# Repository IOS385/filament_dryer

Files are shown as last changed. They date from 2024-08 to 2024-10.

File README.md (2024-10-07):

# 3D Printer Filament Dryer Project
---
<p align="center">
Dryer
</p>

---
This project involves the development of a PCB designed to integrate the **Franzininho C0** with various interfaces for power, sensor reading, and load actuation.
---
<p align="center">
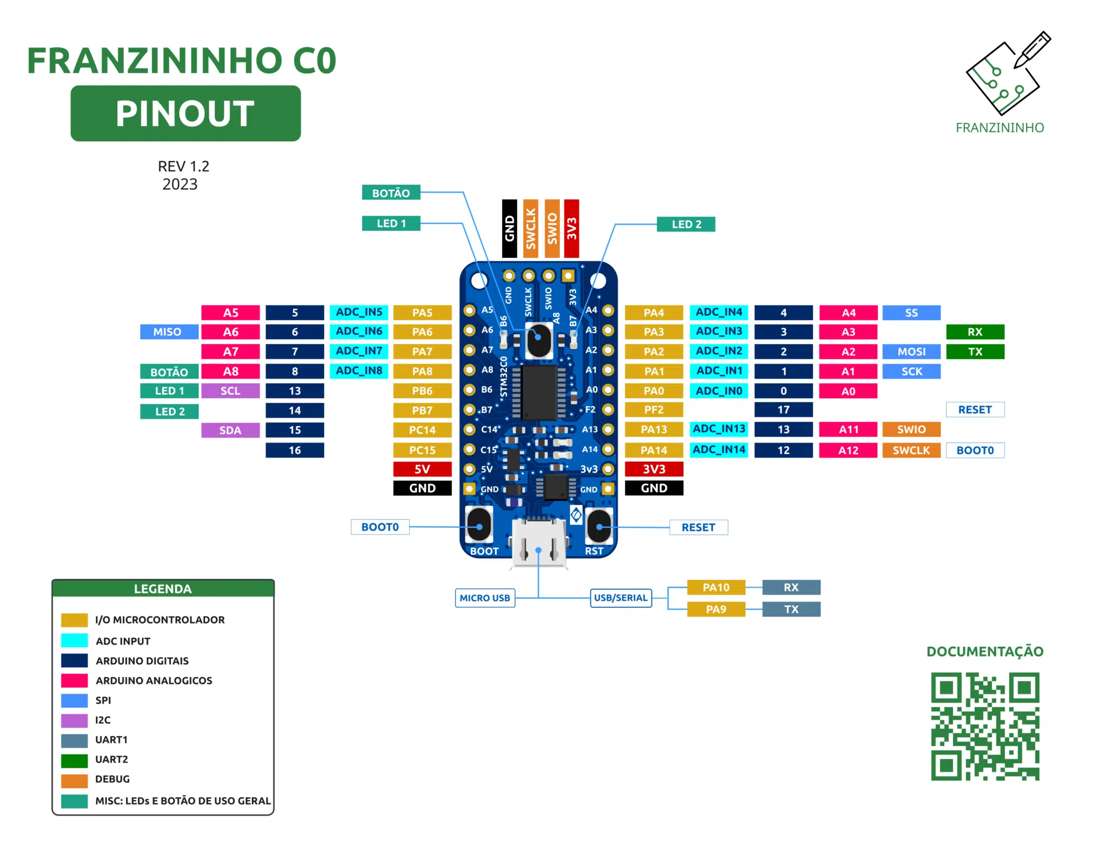
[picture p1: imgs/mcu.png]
Franzininho

</p>

---
## Key Features:
- Mosfet Driver to DC loads
- AC Driver to SSR control and ZeroCrossing detection
- Interface to LCD Display with I2C
- Relay Driver to AC or DC loads
- Analog temperature sensor with External NTC
- Digital temperature and humidity sensor (DHT22 or equivalent)
- 4x buttons to customizable functions (Can be external)

**Note:** This is a flexible project that can be used in other applications, such as:

- **Smart thermostat**: Control heating and cooling systems based on temperature and humidity readings.
- **Greenhouse automation**: Manage humidity, temperature, and lighting for plant growth.
- **Water heater controller**: Regulate the temperature of water in residential or industrial settings.
- **Home automation**: Control devices like fans, lights, or appliances using sensor inputs.
- **Aquarium climate controller**: Maintain stable temperatures and monitor water quality in aquariums.
- **Dehumidifier control**: Automatically manage a dehumidifier based on humidity sensor readings.
- **Food dehydrator**: Control heating elements to dry food for preservation.

The only limit is your creativity.

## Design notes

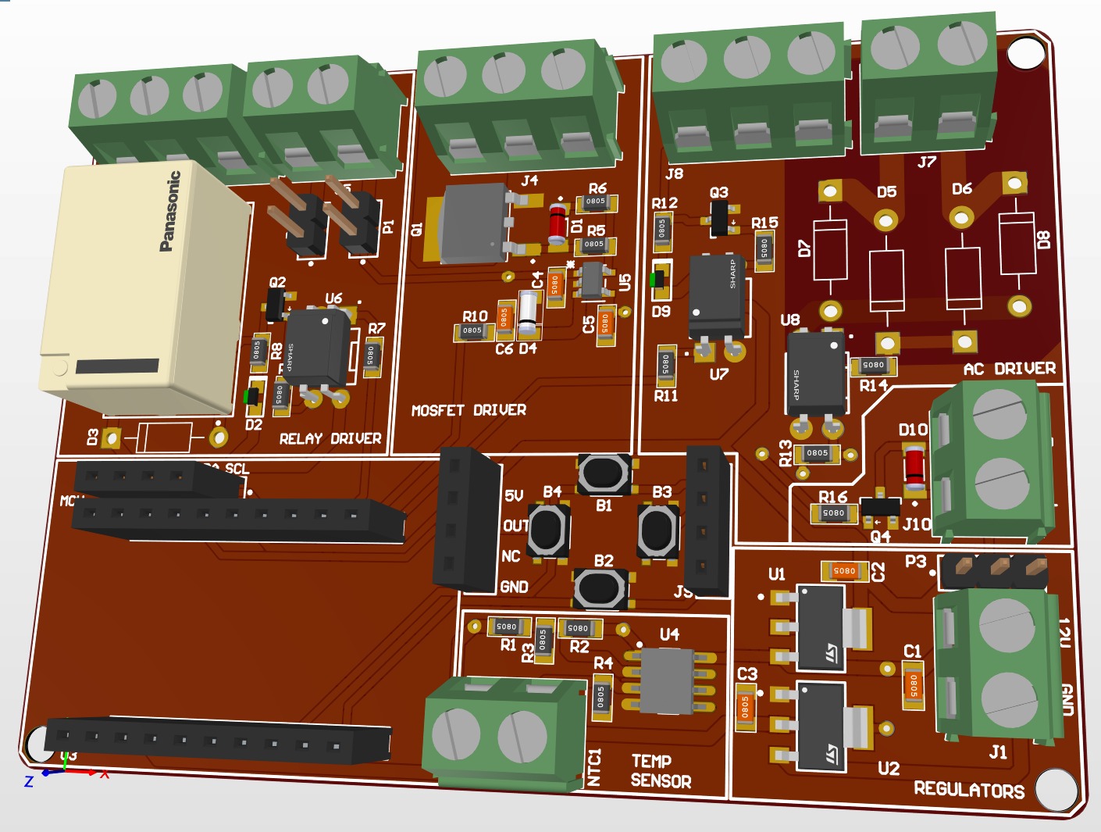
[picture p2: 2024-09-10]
imgs/pcb.jpeg

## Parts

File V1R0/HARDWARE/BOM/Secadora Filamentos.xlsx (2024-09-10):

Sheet: Secadora Filamentos
Name | Designator | Description | Quantity | Manufacturer 1 | Manufacturer Part Number 1
434133025816 | B1, B2, B3, B4 | 434133025816 Tactile Switch, 0.05A, 16Vdc, 160Gf, Smd Rohs Compliant: Yes |Wurth Elektronik 434133025816 | 4 | Wurth Electronics | 434133025816
1µF | C1, C2, C3, C4, C5, C6 | CAP CER 1UF 25V X7R 0805 | 6 | Wurth Electronics | 885012207078
LL4148 | D1 | DIODE GEN PURP 100V 200MA SOD80 | 1 | ON Semiconductor / Fairchild | LL4148
GREEN | D9 | LED GREEN CLEAR 0603 SMD R/A | 1 | Wurth Electronics | 150060GS55040
RED | D2 | LED RED CLEAR 0603 SMD R/A | 1 | Wurth Electronics | 150060RS55040
1kV 1A | D3, D5, D6, D7, D8 | DIODE GEN PURP 1KV 1A DO41 | 5 | Diodes | 1N4007G-T
5.6V | D4 | DIODE ZENER 5.6V 500MW LLDS | 1 | Nexperia | BZV55-C5V6,135
691213710002 | J1, J5, J7, NTC1 | WR-TBL 2P | 4 | Wurth Electronics | 691213710002
61300411821 | J2, J3, J9 | Socket Header 4P 1R | 3 | Wurth Electronics | 61300411821
691213710003 | J4, J6, J8 | WR-TBL 3P | 3 | Wurth Electronics | 691213710003
DK1A-5V-F | K1 | DK1A-5V-F Electromechanical Relay 5VDC 125Ohm 10A SPST-NO (20x12.5x10)mm THT Power Relay | 1 | Panasonic | DK1A-5V-F
61300211121 | P1, P2 | Pin Header 2P 1R | 2 | Wurth Electronics | 61300211121
STD30NF06LT4 | Q1 | Mosfet N-Channel 60V | 1 | STMicroelectronics | STD30NF06LT4
BC817 | Q2, Q3 | TRANS NPN 45V 0.5A SOT23 | 2 | ON Semiconductor | BC817-16LT1G
1K | R1, R3, R7, R8, R9, R11, R12, R15 | RES SMD 1K OHM 1% 1/8W 0805 | 8 | Stackpole Electronics | RMCF0805FT1K00
1K5 | R2 | RES SMD 1K OHM 1% 1/8W 0805 | 1 | Stackpole Electronics | RMCF0805FT1K00
1K37 | R4 | RES SMD 1K OHM 1% 1/8W 0805 | 1 | Stackpole Electronics | RMCF0805FT1K00
22R | R5 | RES SMD 1K OHM 1% 1/8W 0805 | 1 | Stackpole Electronics | RMCF0805FT1K00
4R7 | R6 | RES SMD 1K OHM 1% 1/8W 0805 | 1 | Stackpole Electronics | RMCF0805FT1K00
470R | R10 | RES SMD 1K OHM 1% 1/8W 0805 | 1 | Stackpole Electronics | RMCF0805FT1K00
4K7 | R13 | RES SMD 1K OHM 1% 1/8W 0805 | 1 | Stackpole Electronics | RMCF0805FT1K00
56K | R14 | RES SMD 1K OHM 1% 1/8W 0805 | 1 | Stackpole Electronics | RMCF0805FT1K00
LDL1117S50R | U1 | IC REG LINEAR 5V 1.2A SOT223 | 1 | STMicroelectronics | LDL1117S50R
LDL1117S33R | U2 | IC REG LINEAR 3V3 1.2A SOT223 | 1 | STMicroelectronics | LDL1117S33R
Franzininho_C0 | U3 | Franzininho_C0 | 1 | Embarcados
LM2904D | U4 | Low-Power Dual Operational Amplifier | 1 | STMicroelectronics | LM2904D
PM8841D | U5 | No Description Available | 1 | STMicroelectronics | PM8841D
PC817 | U6, U7, U8 | Opto Coupler | 3 |  |  | https://www.digikey.com.br/pt/products/detail/american-bright-optoelectronics-corporation/BPC-817-B-BIN/9678142
Franzininho Connection | FR1 | Socket Header 10P 1R | 2 | Wurth Electronics | 61301011821

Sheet: Pedir Wurth
Designator | Description | Quantity | Manufacturer 1 | Manufacturer Part Number 1
B1, B2, B3, B4 | 434133025816 Tactile Switch, 0.05A, 16Vdc, 160Gf, Smd Rohs Compliant: Yes |Wurth Elektronik 434133025816 | 40 | Wurth Electronics | 434133025816
C1, C2, C3, C4, C5, C6 | CAP CER 1UF 25V X7R 0805 | 60 | Wurth Electronics | 885012207078
D9 | LED GREEN CLEAR 0603 SMD R/A | 10 | Wurth Electronics | 150060GS55040
D2 | LED RED CLEAR 0603 SMD R/A | 10 | Wurth Electronics | 150060RS55040
J1, J5, J7, NTC1 | WR-TBL 2P | 40 | Wurth Electronics | 691213710002
J2, J3, J9 | Socket Header 4P 1R | 30 | Wurth Electronics | 61300411821
J4, J6, J8 | WR-TBL 3P | 30 | Wurth Electronics | 691213710003
P1, P2 | Pin Header 2P 1R | 20 | Wurth Electronics | 61300211121
FR1 | Socket Header 10P 1R | 20 | Wurth Electronics | 61301011821
U9 | Opto Triac 400VDRM 10mA | 10 | Wurth Electronics | 14230226011
U6, U7, U8 | Opto Coupler | 30 | Wurth Electronics | 140816140410

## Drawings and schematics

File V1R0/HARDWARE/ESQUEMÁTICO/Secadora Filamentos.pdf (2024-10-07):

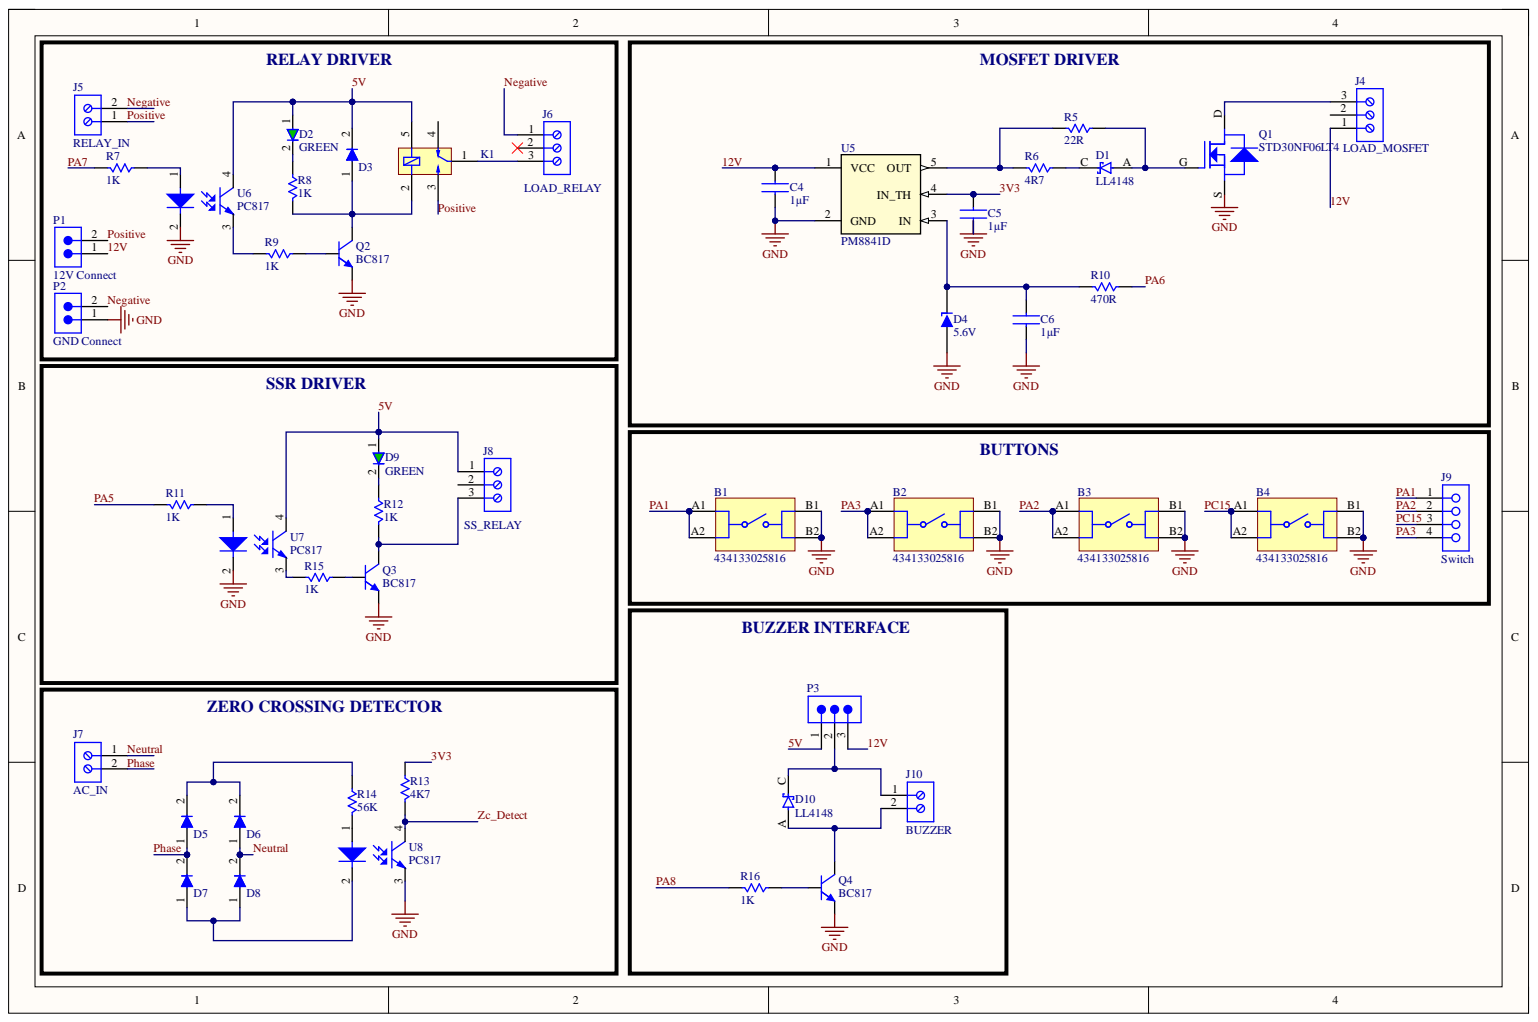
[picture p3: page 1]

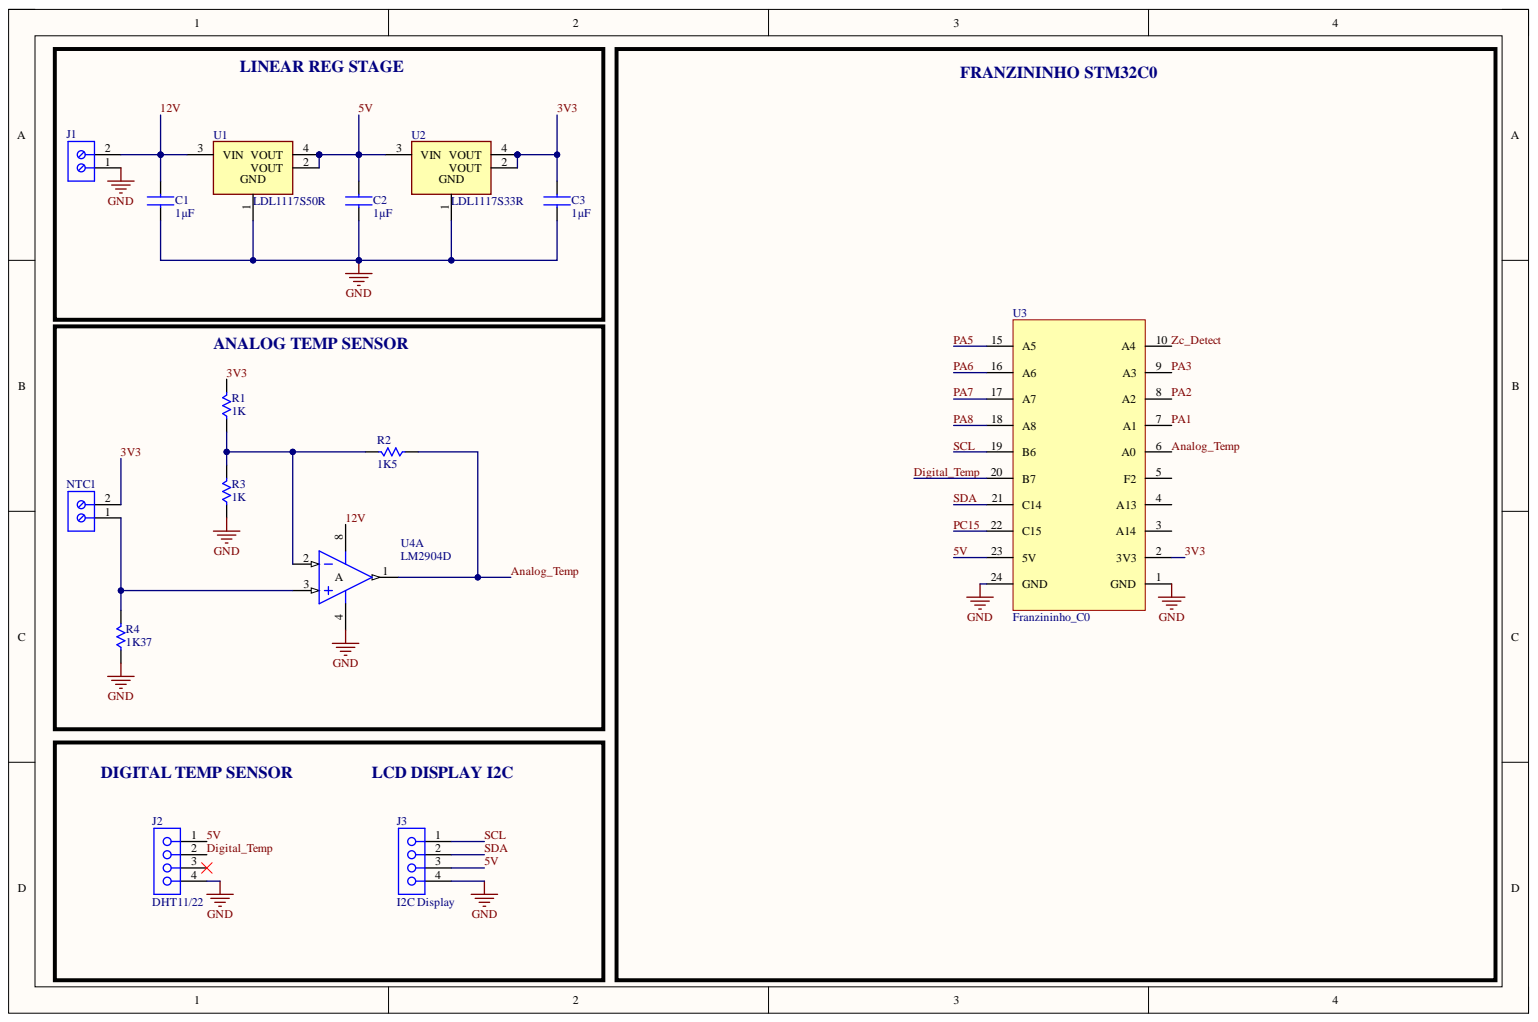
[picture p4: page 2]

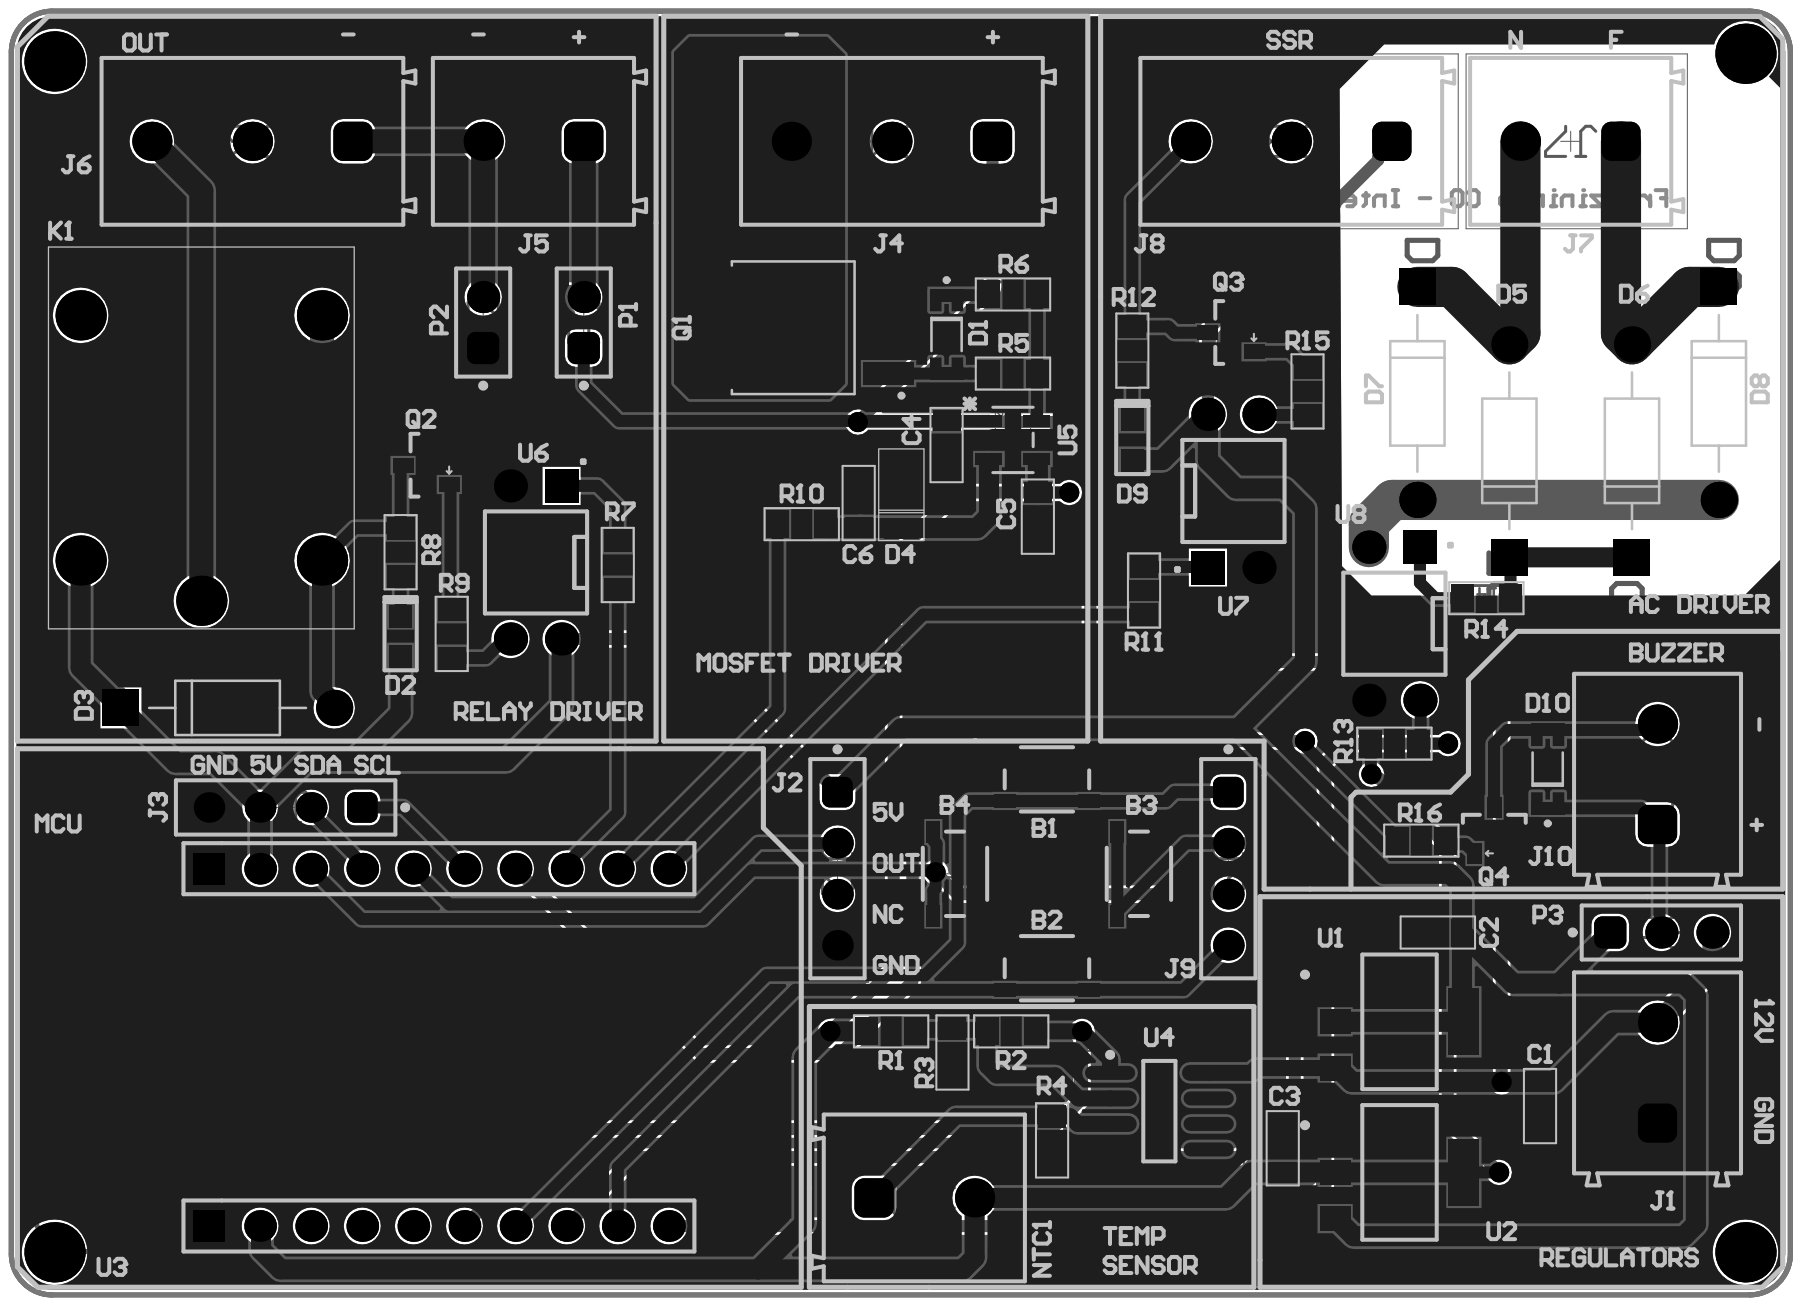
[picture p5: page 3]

Line # | Name | Description | Designator | Revision ID | Revision State | Revision Status | Quantity | Manufacturer 1 | Manufacturer Part Number 1 | Manufacturer Lifecycle 1 | Supplier 1 | Supplier Part Number 1 | Supplier Unit Price 1 | Supplier Subtotal 1
| 691213710002 | | J1, J5, J7, J10, NTC1 | CMP-1502-02526-2 | Released | Up to date | 5 Wurth Electronics | | 691213710002 | Volume Production | Mouser | 710-691213710002 | 0,93 | 4,65
| 61300411821 | | J2, J3, J9 | CMP-1502-01316-3 | Released | Up to date | 3 Wurth Electronics | | 61300411821 | Unknown | Digikey | 732-61300411821-ND | 0,44 | 1,32
| 691213710003 | | J4, J6, J8 | CMP-1502-02527-2 | Released | Up to date | 3 Wurth Electronics | | 691213710003 | End of Life | Mouser | 710-691213710003 | 1,44 | 4,32
| 61300211121 | | P1, P2 | CMP-1712-00002-6 | Released | Up to date | 2 Wurth Electronics | | 61300211121 | Volume Production | Mouser | 710-61300211121 | 0,13 | 0,26
| 61300311121 | | P3 | CMP-1502-01062-3 | Released | Up to date | 1 | Wurth Electronics | 61300311121 | Volume Production | Digikey | 732-5316-ND | 0,13 | 0,13
| STD30NF06LT4 | | Q1 | | Not managed | | 1
| Franzininho_C0 | | U3 | | Not managed | | 1
| 434133025816 | 434133025816 Tactile Switch, 0.05A, 16Vdc, 160Gf, Smd Rohs Compliant: Yes |Wurth Elektronik 434133025816 | B1, B2, B3, B4 | CMP-03913-99472342-1 | New From Design | Up to date | 4 Wurth Electronics | | 434133025816 | Unknown | Digikey | 732-13663-1-ND | 0,54 | 2,16
| 1µF | CAP CER 1UF 25V X7R 0805 | C1, C2, C3, C4, C5, C6 | | Not managed | | 6 Sams | | CL21B105KAFNNNE | Unknown | Digi-Key | 709-1171-1-ND
| 1kV 1A | DIODE GEN PURP 1KV 1A DO41 | D3, D5, D6, D7, D8 | | Not managed | | 5 Diodes | | 1N4007G-T | Volume Production | Digikey | 1N4007GDICT-ND | 0,27 | 1,35
| LL4148 | DIODE GEN PURP 100V 200MA SOD80 | D1, D10 | | Not managed | | 2 ON Semiconductor / | Fairchild | LL4148 | Volume Production | Digikey | LL4148FSCT-ND | 0,11 | 0,22
| 5.6V | DIODE ZENER 5.6V 500MW LLDS | D4 | | Not managed | | 1 | Nexperia | BZV55-C5V6,135 | Volume Production | Digikey | 1727-1888-1-ND | 0,14 | 0,14
| LDL1117S33R | IC REG LINEAR 3V3 1.2A SOT223 | U2 | | Not managed | | 1
| LDL1117S50R | IC REG LINEAR 5V 1.2A SOT223 | U1 | | Not managed | | 1
| GREEN | LED GREEN CLEAR 0603 SMD R/A | D2, D9 | | Not managed | | 2 Inolux | | IN-S63ASG | Unknown | Digikey | 1830-1030-1-ND | 0,39 | 0,78
| LM2904D | Low-Power Dual Operational Amplifier | U4 | | Not managed | | 1
| PM8841D | No Description Available | U5 | | Not managed | | 1
| PC817 | Opto Coupler | U6, U7, U8 | | Not managed | | 3
| AX1RC2 | RELAY GEN PURPOSE SPDT 15A 12V | K1 | | Not managed | | 1 | MELTALTEX | AX1RC2
| 1K | RES SMD 1K OHM 1% 1/8W 0805 | R1, R3, R7, R8, R9, R11, R12, R15, R16 | | Not managed | | 9 Stackpole Electronics | | RMCF0805FT1K00 | Volume Production | Digikey | RMCF0805FT1K00CT-ND | 0,02 | 0,2
| 1K5 | RES SMD 1K OHM 1% 1/8W 0805 | R2 | | Not managed | | 1 | Stackpole Electronics | RMCF0805FT1K00 | Volume Production | Digikey | RMCF0805FT1K00CT-ND | 0,1 | 0,1
| 1K37 | RES SMD 1K OHM 1% 1/8W 0805 | R4 | | Not managed | | 1 | Stackpole Electronics | RMCF0805FT1K00 | Volume Production | Digikey | RMCF0805FT1K00CT-ND | 0,1 | 0,1
| 22R | RES SMD 1K OHM 1% 1/8W 0805 | R5 | | Not managed | | 1 | Stackpole Electronics | RMCF0805FT1K00 | Volume Production | Digikey | RMCF0805FT1K00CT-ND | 0,1 | 0,1
| 4R7 | RES SMD 1K OHM 1% 1/8W 0805 | R6 | | Not managed | | 1 | Stackpole Electronics | RMCF0805FT1K00 | Volume Production | Digikey | RMCF0805FT1K00CT-ND | 0,1 | 0,1
| 470R | RES SMD 1K OHM 1% 1/8W 0805 | R10 | | Not managed | | 1 | Stackpole Electronics | RMCF0805FT1K00 | Volume Production | Digikey | RMCF0805FT1K00CT-ND | 0,1 | 0,1
| 4K7 | RES SMD 1K OHM 1% 1/8W 0805 | R13 | | Not managed | | 1 | Stackpole Electronics | RMCF0805FT1K00 | Volume Production | Digikey | RMCF0805FT1K00CT-ND | 0,1 | 0,1
| 56K | RES SMD 1K OHM 1% 1/8W 0805 | R14 | | Not managed | | 1 | Stackpole Electronics | RMCF0805FT1K00 | Volume Production | Digikey | RMCF0805FT1K00CT-ND | 0,1 | 0,1
| BC817 | TRANS NPN 45V 0.5A SOT23 | Q2, Q3, Q4 | | Not managed | | 3 ON Semiconductor | | BC817-16LT1G | Volume Production | Digikey | BC817-16LT1GOSCT-ND | 0,15 | 0,45

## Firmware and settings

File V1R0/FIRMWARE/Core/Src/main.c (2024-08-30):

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
/* Includes ------------------------------------------------------------------*/
#include "main.h"

/* USER CODE BEGIN Includes */
#include <math.h>
/* USER CODE END Includes */

ADC_HandleTypeDef hadc1;
DMA_HandleTypeDef hdma_adc1;

TIM_HandleTypeDef htim3;
TIM_HandleTypeDef htim16;

/* USER CODE BEGIN PV */
uint32_t adc;
float tensao;
float temperature;
float R1 = 10000;
float logR2, R2, T;
float j;
float c1 = 1.009249522e-03, c2 = 2.378405444e-04, c3 = 2.019202697e-07;

//PID VARIABLES
float Kp = 2.2;
float Ki = 0.0001;
float Kd = 0;
float Erro_Anterior = 0;
float Erro = 0;
float SetPoint = 20;
float u_gain = 1;

float P = 0;
float I = 0;
float D = 0;

float Saida = 0;
float Saida_Anterior = 0;
float Temp_Anterior = 0;
int t = 1000;

/* USER CODE END PV */

void SystemClock_Config(void);
static void MX_GPIO_Init(void);
static void MX_DMA_Init(void);
static void MX_ADC1_Init(void);
static void MX_TIM3_Init(void);
static void MX_TIM16_Init(void);
/**
  * @brief  The application entry point.
  * @retval int
  */
int main(void)
{

  /* MCU Configuration--------------------------------------------------------*/

  /* Reset of all peripherals, Initializes the Flash interface and the Systick. */
  HAL_Init();

  /* Configure the system clock */
  SystemClock_Config();

  /* Initialize all configured peripherals */
  MX_GPIO_Init();
  MX_DMA_Init();
  MX_ADC1_Init();
  MX_TIM3_Init();
  MX_TIM16_Init();
  /* USER CODE BEGIN 2 */
  HAL_ADCEx_Calibration_Start(&hadc1);
  HAL_ADC_Start_DMA(&hadc1, &adc, 1);
  HAL_TIM_Base_Start(&htim3);
  HAL_TIM_PWM_Start(&htim16, TIM_CHANNEL_1);

  //HAL_TIM_Base_Start(&htim3);


  /* USER CODE END 2 */

  /* Infinite loop */
  /* USER CODE BEGIN WHILE */
  while (1)
  {
    /* USER CODE END WHILE */

    /* USER CODE BEGIN 3 */
      if(HAL_GPIO_ReadPin(BOTAO_GPIO_Port, BOTAO_Pin)==0){ //leitura botao
          HAL_GPIO_TogglePin(GPIOB, LED1_Pin); //alterna estado pinos
          HAL_Delay(20); //20ms
      }
      //
      j = 4095/(float)adc;
      R2 = R1 * (j - 1.0);
      logR2 = log(R2);
      temperature = (1.0 / (c1 + c2*logR2 + c3*logR2*logR2*logR2));
      temperature = temperature - 273.15;
      //temperature = (T * 9.0)/ 5.0 + 32.0;
	  Erro = SetPoint - temperature;


	  P = Erro * Kp;

	  I = (Ki * (Erro + Erro_Anterior))*(t);

	  D = (Kd * (Temp_Anterior - temperature))*(t);

	  Saida = ((P+I+D)*u_gain) + Saida_Anterior;

	  //Saida = 1000 - Saida;

	  if(Saida<0)
	  {
		  Saida = 0;
		  Erro = 0;
	  }
	  else if(Saida>999)
	  {
		  Saida = 999;
		  Erro = 0;
	  }

	  TIM16->CCR1 = (uint32_t)Saida;

	  Erro_Anterior = Erro;
	  Saida_Anterior = Saida;
	  Temp_Anterior = temperature;

	  HAL_Delay(t);


  }
  /* USER CODE END 3 */
}

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


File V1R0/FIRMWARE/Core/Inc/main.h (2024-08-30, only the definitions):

#define BOTAO_Pin GPIO_PIN_8
#define BOTAO_GPIO_Port GPIOA
#define LED1_Pin GPIO_PIN_6
#define LED1_GPIO_Port GPIOB

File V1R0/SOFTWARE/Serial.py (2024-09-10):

import serial  # used to open serial port
import serial.tools.list_ports  # used to list the avaliable serial ports

def print_available_com_ports():
    """ Prints all the available serial ports
    :returns: A list of the serial ports available on the system
    """
    ports = serial.tools.list_ports.comports()
    print("Available COM ports:")
    port_found_n = 0
    for port, description, hw_id in sorted(ports):
        if description.startswith("STMicroelectronics STLink Virtual COM Port") or \
                description.startswith("Silicon Labs Dual CP2105 USB to UART Bridge:"):
            print("\t{}".format(description))
            port_found_n += 1

    if port_found_n == 0:
        print("\tNo compatible COM port found")
    print("")


def send_msg(ser, msg, wait_answer=True):
    bytes(msg)
    ser.write(msg)
    if wait_answer:
        response = read_msg(ser)
        return response

    return None

def read_msg(ser):
    msg = ser.read()
    print(msg)
    return msg


if __name__ == "__main__":
    print_available_com_ports()
    port_name_cord = input(
        "Enter the serial port name for the coordinator (e.g., COM1 or /dev/ttyUSB0): ")
    
    baud_rate = 115200  # standart baud_rate
    ser = serial.Serial(port_name_cord, baud_rate, timeout=3)
    msg = 30
    
    send_msg(ser, msg)
    
    

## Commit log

2024-08-29 first commit for a filament_dryer
    [FranzininhoC0.SchDoc, Interfaces.SchDoc, PCB1.PcbDoc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]
2024-08-30 Added firmware and hardware paths
    [FranzininhoC0.SchDoc, Interfaces.SchDoc, PCB1.PcbDoc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]
2024-08-30 Added SSR interface instead Triac Driver, to control more power plants
    [Interfaces.SchDoc, PCB1.PcbDoc]
2024-08-30 Beginning route / Library fixes
    [FranzininhoC0.SchDoc, PCB1.PcbDoc, Secadora Filamentos.PrjPcb]
2024-08-31 Polygon placement
    [PCB1.PcbDoc, Secadora Filamentos.PrjPcb]
2024-09-09 BoM generated and DRC checked
    [Secadora Filamentos.xlsx]
2024-09-09 Gerbers Generated and Buzzer Interface Added
    [FranzininhoC0.SchDoc, Interfaces.SchDoc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]
2024-09-09 Fixed Top Overlay
    [PCB1.GBL, PCB1.GBO, PCB1.GBP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]
2024-09-09 Sch pdf Created
    [FranzininhoC0.SchDoc]
2024-09-09 Revision PCB
    [Interfaces.SchDoc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]
2024-09-09 Minor fix
    [PCB1.PcbDoc]
2024-09-09 Added tool paht
    [PCB1.GBL, PCB1.GBO, PCB1.GBP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]
2024-09-09 PCB okay
    [PCB1.PcbDoc]
2024-09-10 Relay PN changed and PCB updated
    [Interfaces.SchDoc, PCB1.PcbDoc]
2024-09-10 Regenerated gerber files
    [PCB1.GBL, PCB1.GBO, PCB1.GBP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]
2024-09-10 Added pcb1 image
2024-10-07 Mechanical fixes
    Standard Dimensions
    [PCB1.PcbDoc]
2024-10-14 Updating Franzininho PCB Library
2024-10-15 Gerbers Franzininho Added to Lib
2024-10-25 Files organization
    [FranzininhoC0.SchDoc, Interfaces.SchDoc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]

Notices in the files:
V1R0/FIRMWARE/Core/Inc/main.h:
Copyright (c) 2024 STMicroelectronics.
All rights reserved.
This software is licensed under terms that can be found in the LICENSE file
